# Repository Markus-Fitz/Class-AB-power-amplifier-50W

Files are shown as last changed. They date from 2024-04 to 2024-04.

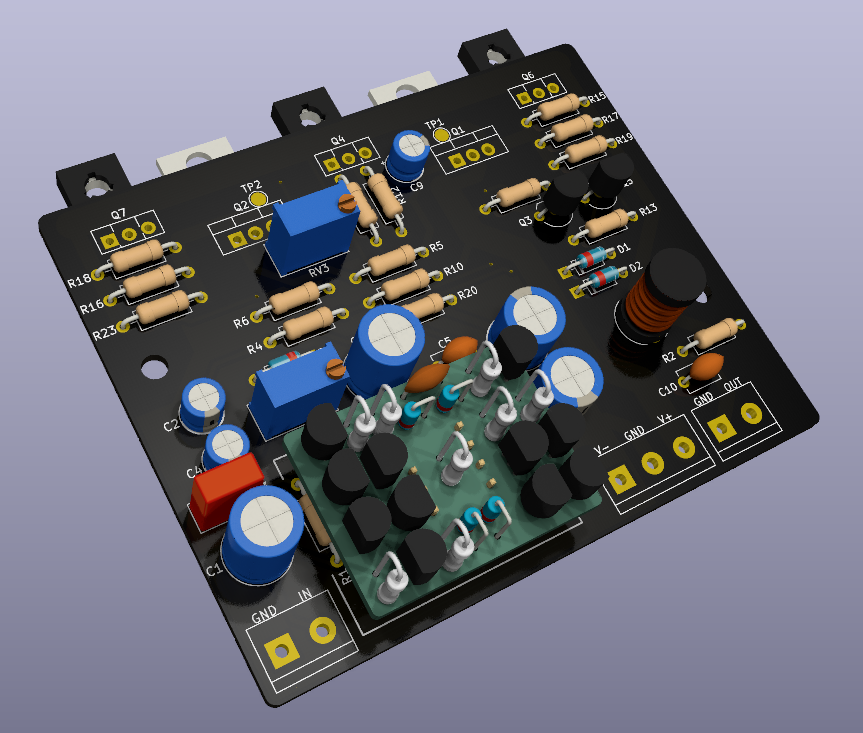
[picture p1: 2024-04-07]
render_top.png

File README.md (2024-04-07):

# Class-AB-power-amplifier-50W
 Class AB power amplifier designed for 25W into 8 Ohms and 50W into 4 Ohms.

# Specs
 This Power amplifier consists of a Darlington-pair of TIP41C- and BD139-transistors and TIP42C- and BD140-transistors. This amplifier was designed for the operation with a +-24V power-supply. The voltage-amplification is done with a OpAmp, which therefore has to withstand the maximum supply voltages. A Vbe-multiplier mounted to the same heatsink is responsible for a stable bias current throung the endstage and can be adjusted for different bias current settings.

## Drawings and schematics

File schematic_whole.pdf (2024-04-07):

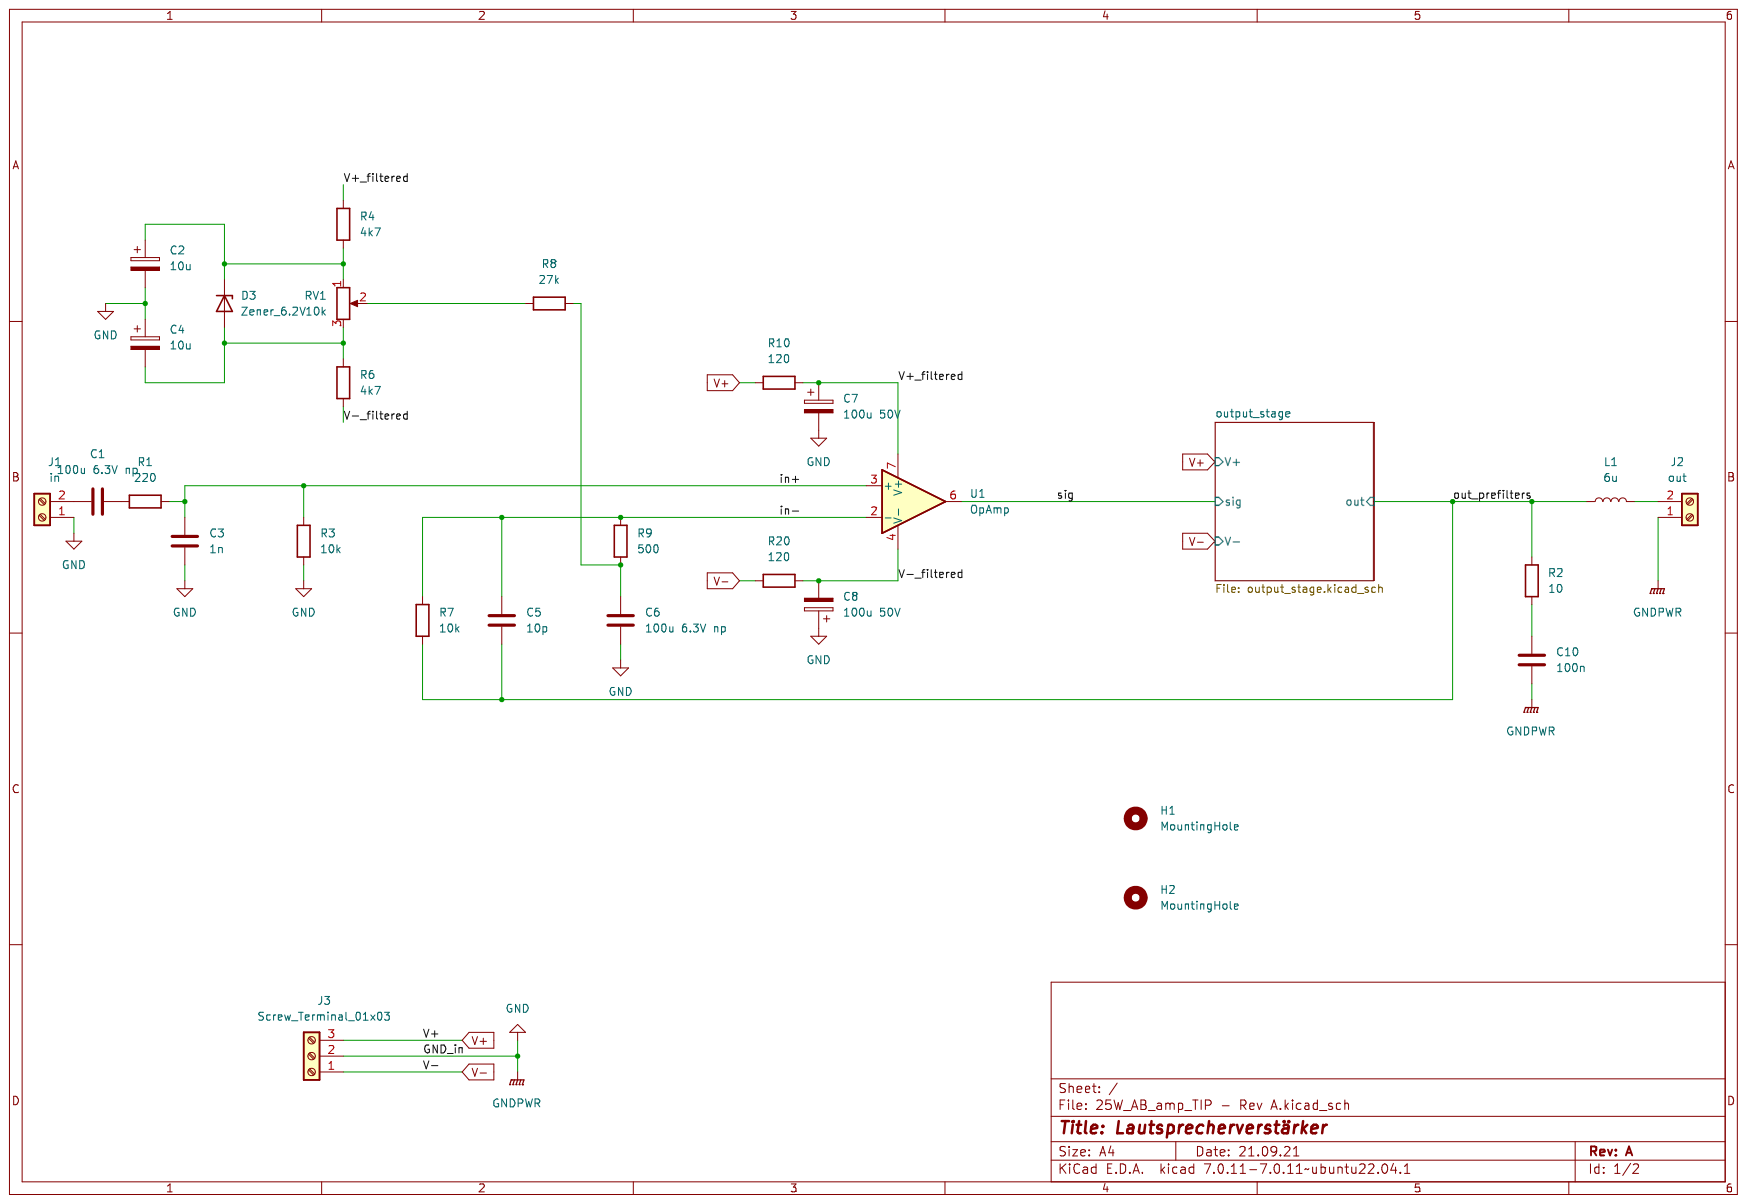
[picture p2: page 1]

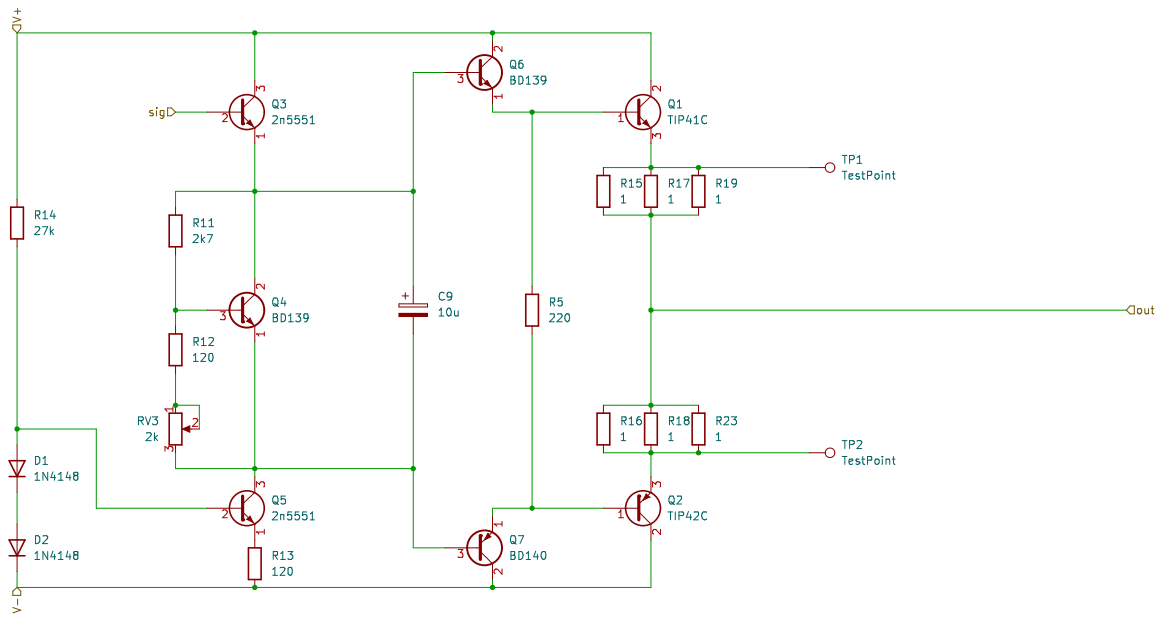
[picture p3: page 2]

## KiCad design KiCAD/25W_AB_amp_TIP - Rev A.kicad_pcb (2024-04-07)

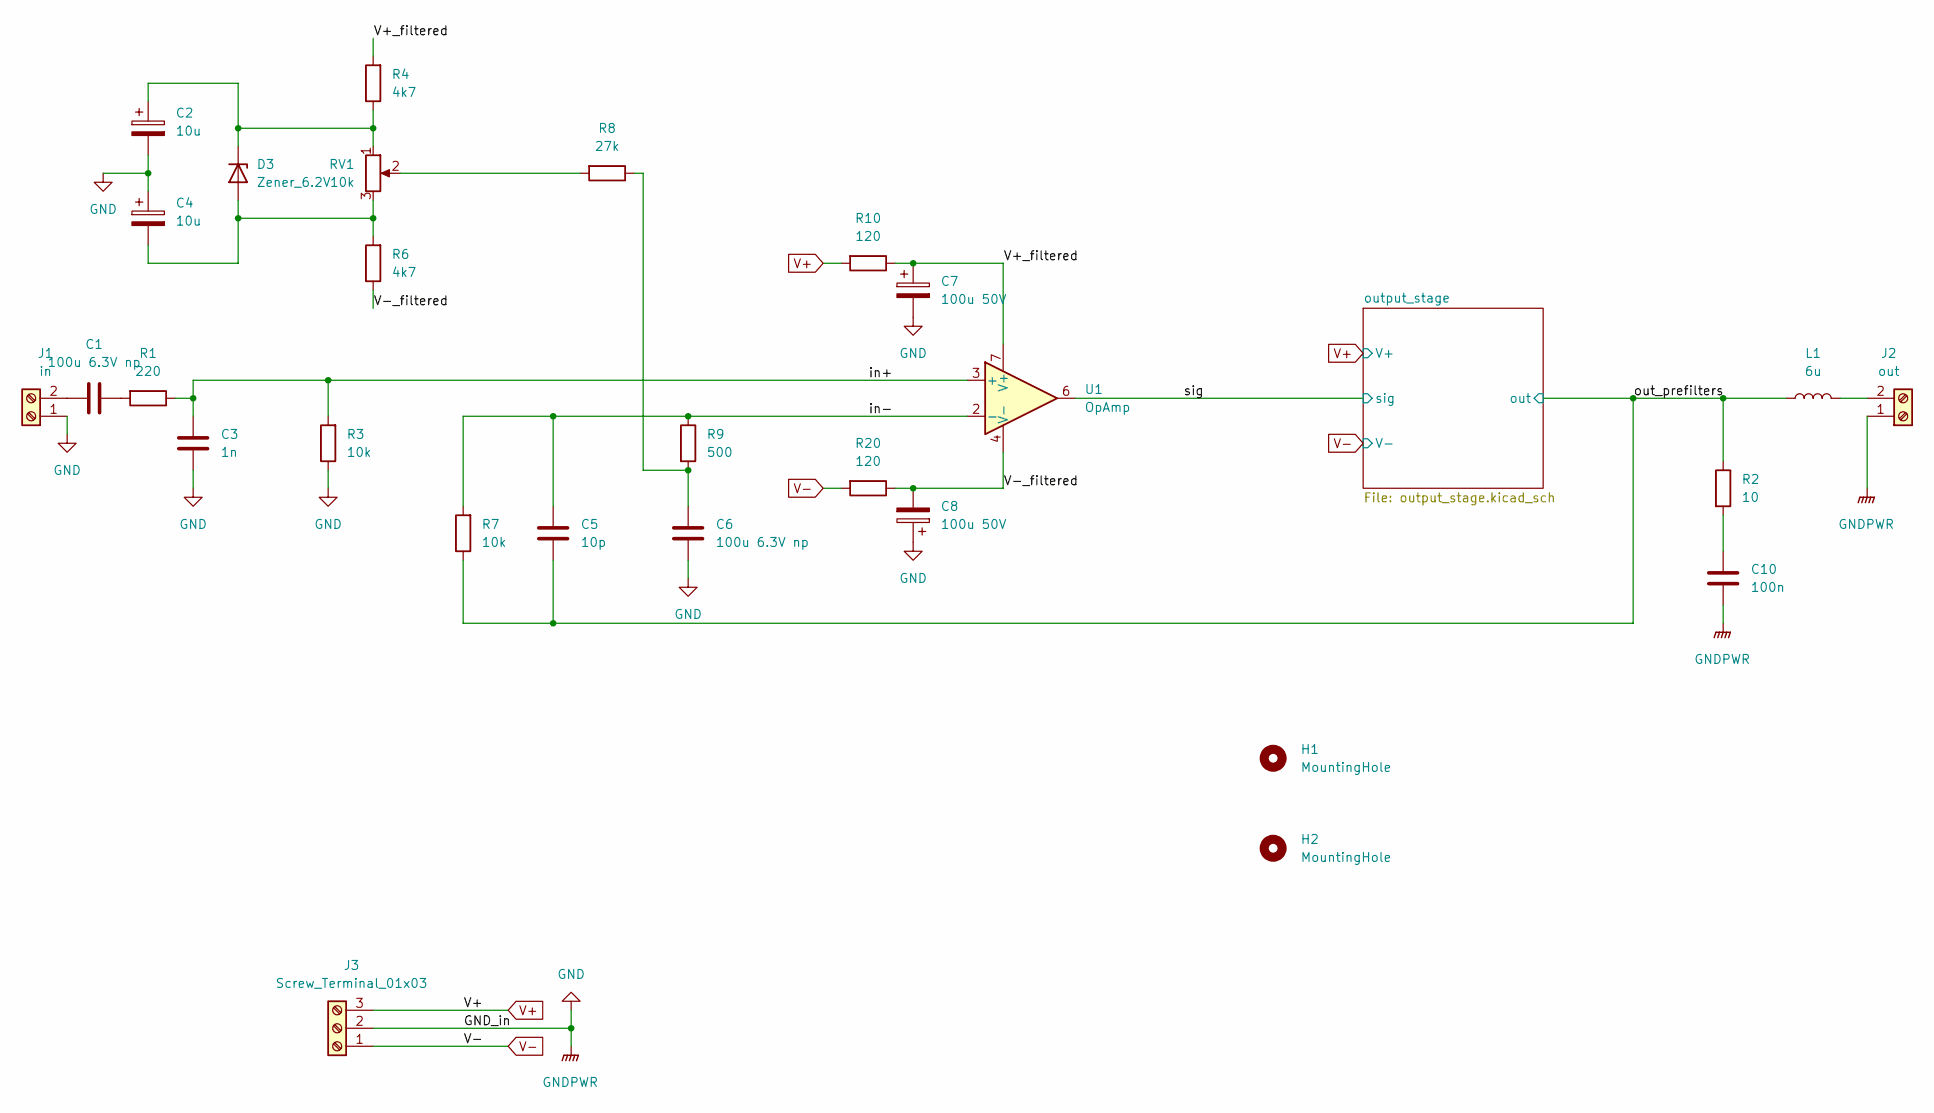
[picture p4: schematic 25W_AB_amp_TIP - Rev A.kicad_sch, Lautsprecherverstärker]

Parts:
C1, C6: 100u 6.3V np; C_Radial_D8.0mm_H11.5mm_P3.50mm
C2, C4: 10u; CP_Radial_D5.0mm_P2.00mm
C3: 1n; C_Rect_L7.0mm_W3.5mm_P5.00mm
C5: 10p; C_Disc_D5.1mm_W3.2mm_P5.00mm
C7, C8: 100u 50V; CP_Radial_D8.0mm_P3.50mm
C10: 100n; C_Disc_D5.1mm_W3.2mm_P5.00mm
D3: Zener_6.2V; D_DO-35_SOD27_P7.62mm_Horizontal
H1, H2: MountingHole; MountingHole_3.2mm_M3
J1: in; TerminalBlock_bornier-2_P5.08mm
J2: out; TerminalBlock_bornier-2_P5.08mm
J3: Screw_Terminal_01x03; TerminalBlock_bornier-3_P5.08mm
L1: 6u; L_Radial_D7.5mm_P5.00mm_Fastron_07P
R1: 220; R_Axial_DIN0207_L6.3mm_D2.5mm_P10.16mm_Horizontal
R2: 10; R_Axial_DIN0207_L6.3mm_D2.5mm_P10.16mm_Horizontal
R3, R7: 10k; R_Axial_DIN0207_L6.3mm_D2.5mm_P10.16mm_Horizontal
R4, R6: 4k7; R_Axial_DIN0207_L6.3mm_D2.5mm_P10.16mm_Horizontal
R8: 27k; R_Axial_DIN0207_L6.3mm_D2.5mm_P10.16mm_Horizontal
R9: 500; R_Axial_DIN0207_L6.3mm_D2.5mm_P10.16mm_Horizontal
R10, R20: 120; R_Axial_DIN0207_L6.3mm_D2.5mm_P10.16mm_Horizontal
RV1: 10k; Potentiometer_Bourns_3296W_Vertical
U1: OpAmp; DIP-8_W7.62mm_Socket

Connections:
/V+_filtered: C7.1, R4.2, R10.1, U1.7 (V+)
/V-_filtered: C8.2, R6.1, R20.1, U1.4 (V-)
/in+: C3.1, R1.1, R3.2, U1.3 (+)
/in-: C5.2, R7.2, R9.1, U1.2 (-)
/out_prefilters: C5.1, L1.1, R2.1, R7.1; also elsewhere on the board
/sig: U1.6; also elsewhere on the board
GND: C2.2, C3.2, C4.1, C6.1, C7.2, C8.1, C10.1, J1.1, J2.1, J3.2, R3.1
unnamed: C1.1, J1.2
unnamed: C1.2, R1.2
unnamed: C2.1, D3.1 (K), R4.1, RV1.1
unnamed: C4.2, D3.2 (A), R6.2, RV1.3
unnamed: C6.2, R8.1, R9.2
unnamed: C10.2, R2.2
unnamed: J2.2, L1.2
unnamed: R8.2, RV1.2
V+: J3.3, R10.2; also elsewhere on the board
V-: J3.1, R20.2; also elsewhere on the board

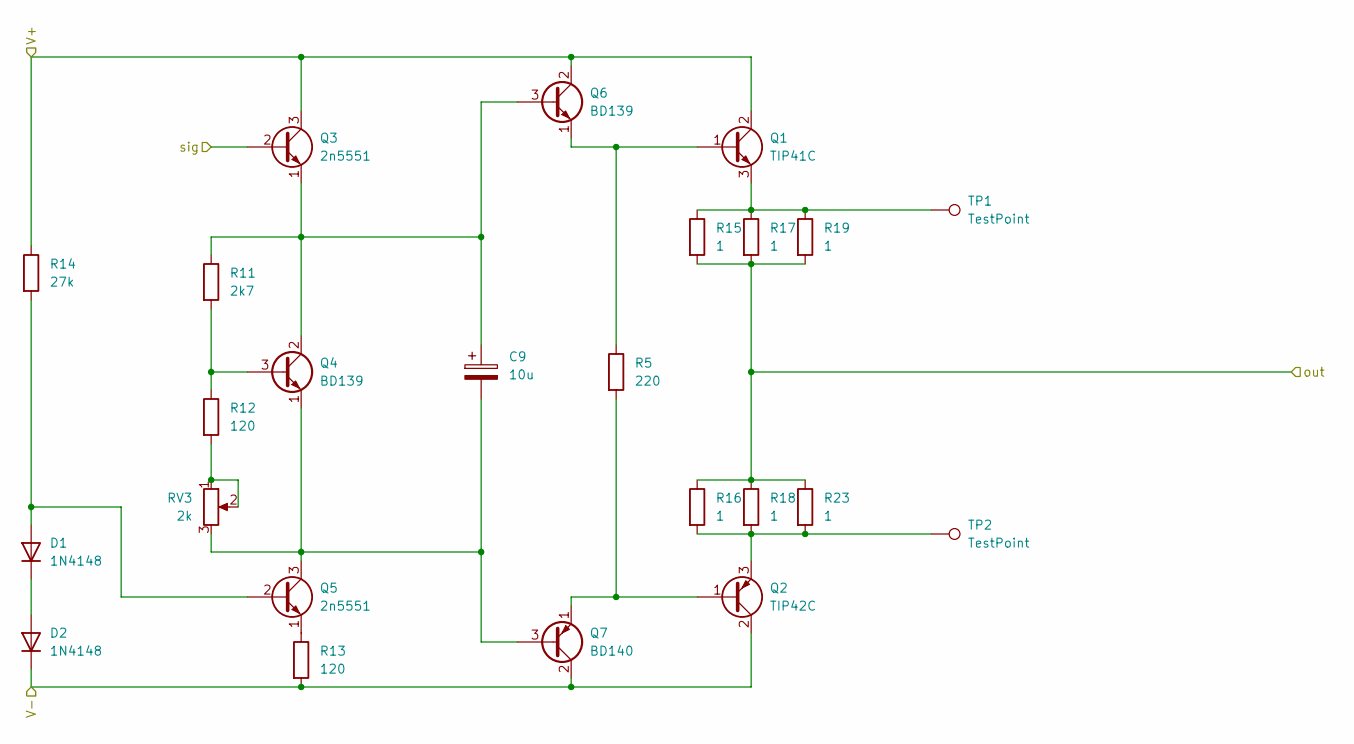
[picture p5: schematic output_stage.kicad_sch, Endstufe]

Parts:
C9: 10u; CP_Radial_D5.0mm_P2.00mm
D1, D2: 1N4148; D_DO-35_SOD27_P7.62mm_Horizontal
Q1: TIP41C; TO-220-3_Vertical
Q2: TIP42C; TO-220-3_Vertical
Q3, Q5: 2n5551; TO-92_Inline_Wide
Q4, Q6: BD139; TO-126-3_Vertical
Q7: BD140; TO-126-3_Vertical
R5: 220; R_Axial_DIN0207_L6.3mm_D2.5mm_P10.16mm_Horizontal
R11: 2k7; R_Axial_DIN0207_L6.3mm_D2.5mm_P10.16mm_Horizontal
R12, R13: 120; R_Axial_DIN0207_L6.3mm_D2.5mm_P10.16mm_Horizontal
R14: 27k; R_Axial_DIN0207_L6.3mm_D2.5mm_P10.16mm_Horizontal
R15, R16, R17, R18, R19, R23: 1; R_Axial_DIN0207_L6.3mm_D2.5mm_P10.16mm_Horizontal
RV3: 2k; Potentiometer_Bourns_3296W_Vertical
TP1, TP2: TestPoint; TestPoint_Pad_D2.0mm

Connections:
/out_prefilters: R15.2, R16.1, R17.2, R18.1, R19.2, R23.1; also elsewhere on the board
/sig: Q3.2 (B); also elsewhere on the board
unnamed: C9.1, Q3.1 (E), Q4.2 (C), Q6.3 (B), R11.1
unnamed: C9.2, Q4.1 (E), Q5.3 (C), Q7.3 (B), RV3.3
unnamed: D1.1 (K), D2.2 (A)
unnamed: D1.2 (A), Q5.2 (B), R14.2
unnamed: Q1.1 (B), Q6.1 (E), R5.1
unnamed: Q1.3 (E), R15.1, R17.1, R19.1, TP1.1
unnamed: Q2.1 (B), Q7.1 (E), R5.2
unnamed: Q2.3 (E), R16.2, R18.2, R23.2, TP2.1
unnamed: Q4.3 (B), R11.2, R12.1
unnamed: Q5.1 (E), R13.1
unnamed: R12.2, RV3.1, RV3.2
V+: Q1.2 (C), Q3.3 (C), Q6.2 (C), R14.1; also elsewhere on the board
V-: D2.1 (K), Q2.2 (C), Q7.2 (C), R13.2; also elsewhere on the board

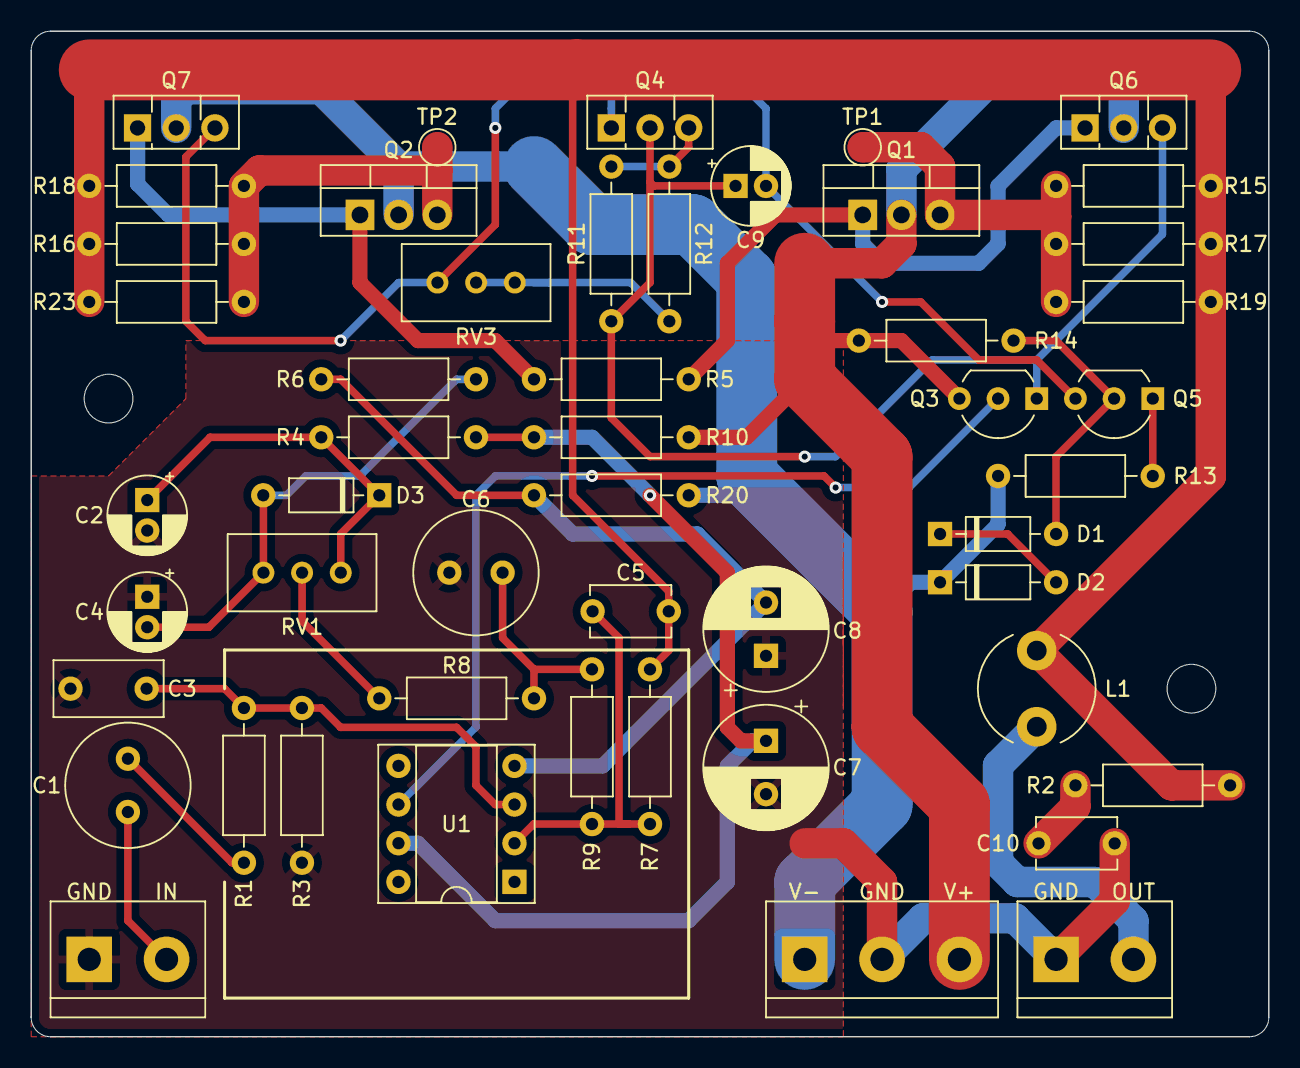
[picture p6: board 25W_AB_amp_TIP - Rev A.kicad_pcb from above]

Board: 2 copper layers, 81.3 x 66.0 mm, 52 parts (0 on the bottom side), 28 nets.
